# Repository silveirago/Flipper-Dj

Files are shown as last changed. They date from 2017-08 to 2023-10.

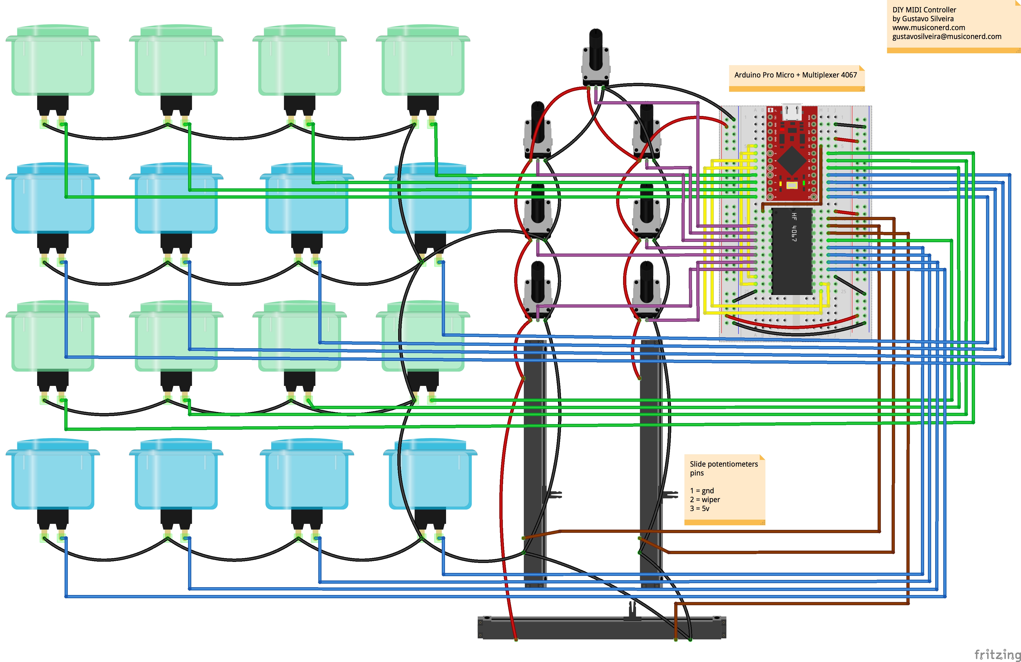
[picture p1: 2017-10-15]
Schematic/Fliper DJ_schematic.jpg

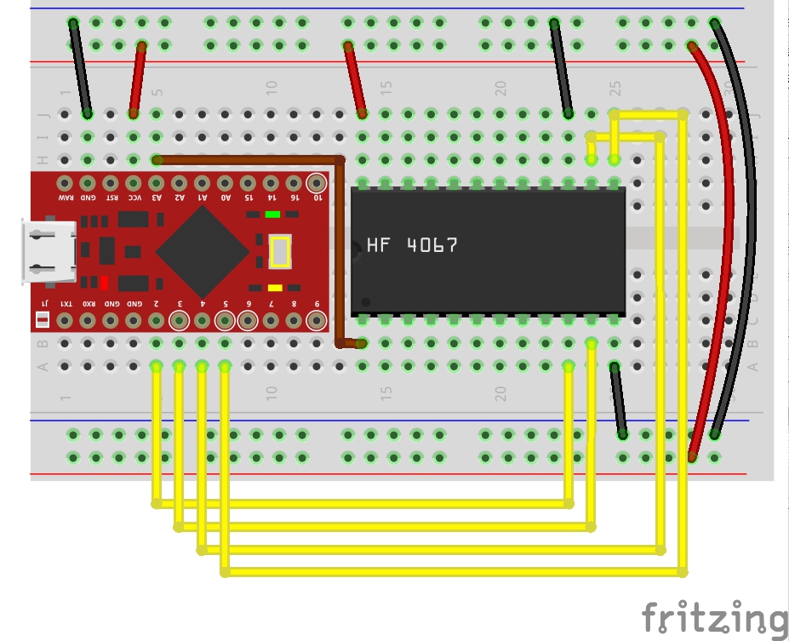
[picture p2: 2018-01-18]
Schematic/CD4067 + Arduino Pro Micro_schematic_bb.jpg

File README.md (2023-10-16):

# Flipper-Dj

Complete tutorial: https://www.musiconerd.com/single-post/Build-this-MIDI-controller-Fliper-Dj

The Fliper DJ is a MIDI controller which is based in the Arduino platform. It contains 16 arcade buttons, 7 rotary potentiometers and 3 slider potentiometers. One of the potentiometers allows you to change the midi channel of the buttons, making it possible to have four banks of buttons, 16x4. The Fliper DJ is a USB-Midi class compliant device, no drivers or converters needed!

Material Needed:

- 16 arcade buttons 30mm
- 7 b10k rotary potentiometers 
- 3 b10k slide potentiometer 30mm (https://www.sparkfun.com/products/11621)
- 1 Arduino Pro Micro
- 1 solderable breadboard (https://www.amazon.com/gp/product/B071R3BFNL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)
- 1 CD40676BE multiplexer
- 5 Spacers M3x35+6mm Female/Male with washers
5 screws M3
- Wires
- 3 guitar pick selector knobs (for the slide pots)
- 7 rotary potentiometer knobs

Some of the items can be found here: https://kit.co/nerdmusician/diy-midi-controller-final-projects-amazon-us

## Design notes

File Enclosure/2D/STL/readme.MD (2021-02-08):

# 3D Printed Enclosures

The files are divided so they fit most beds. Make sure that if you use cura, scale them to 1000%.

Enjoy!

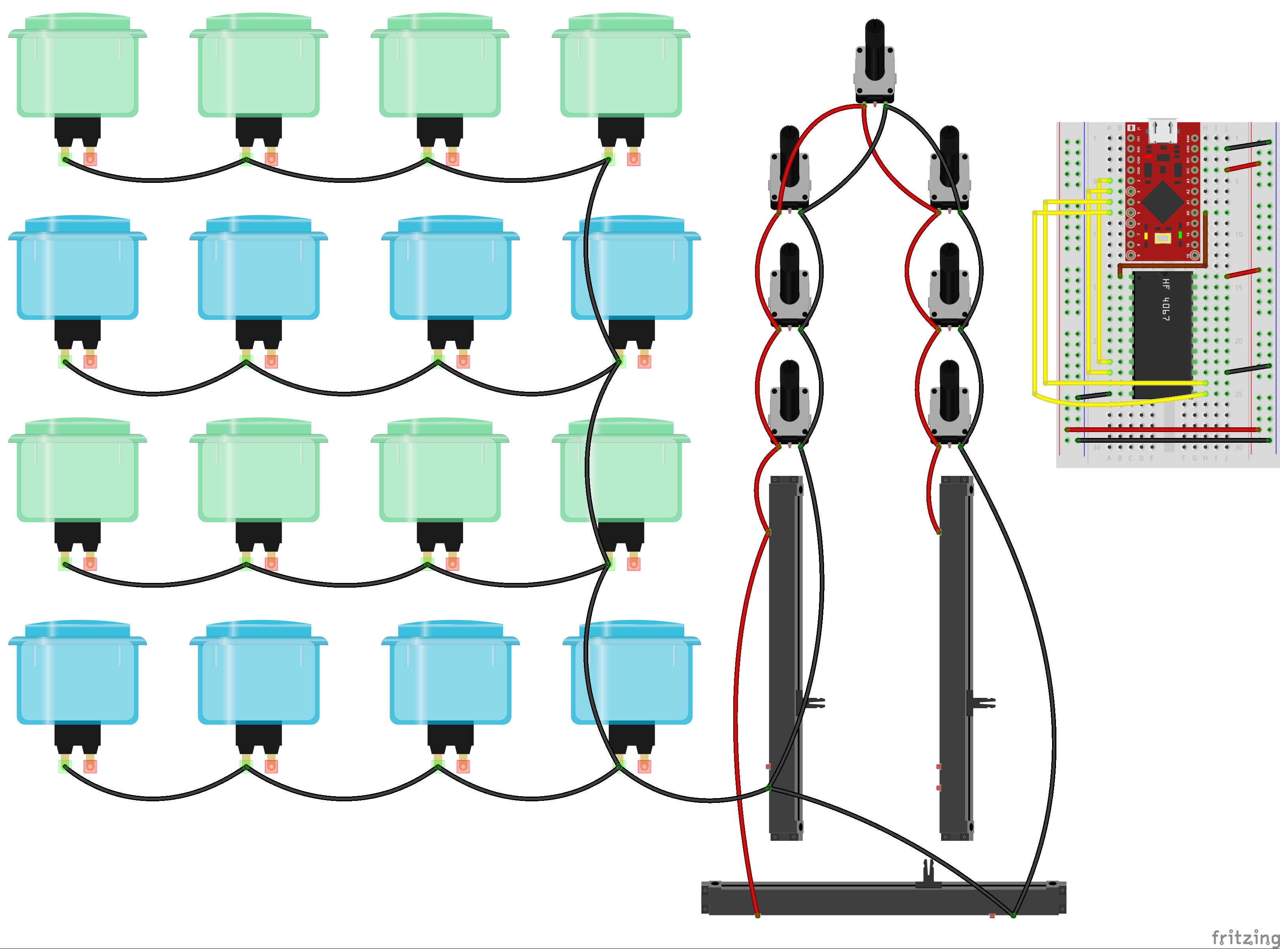
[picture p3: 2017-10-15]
Schematic/Fliper DJ (clean)_schematic.jpg

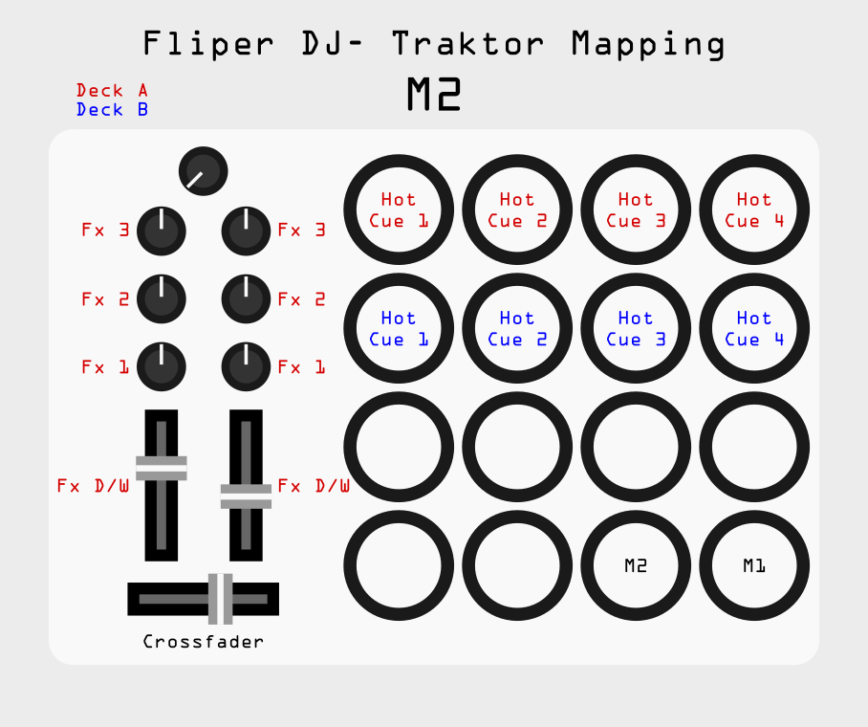
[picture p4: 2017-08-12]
Traktor/Fliper DJ - M2.png

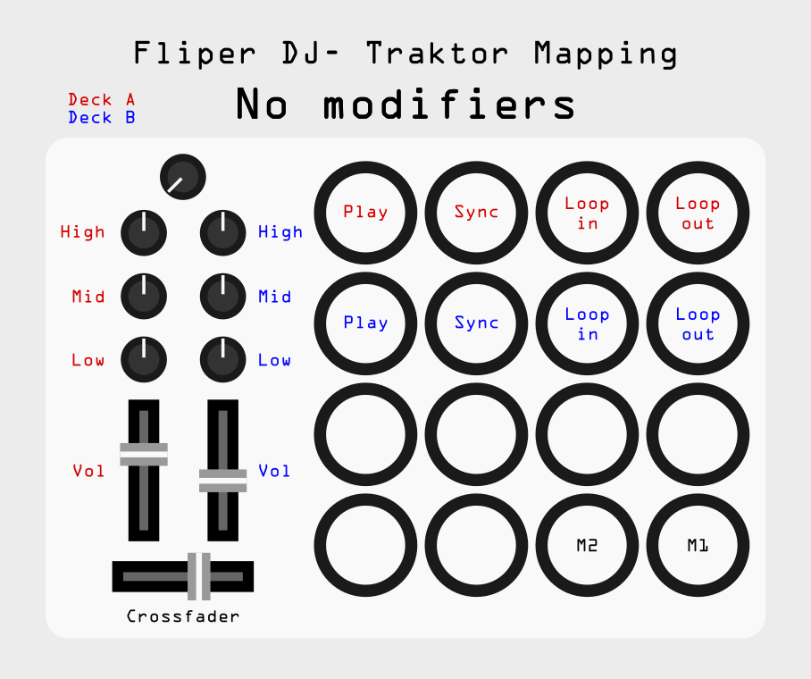
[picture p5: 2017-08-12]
Traktor/Fliper DJ - no modifiers.png

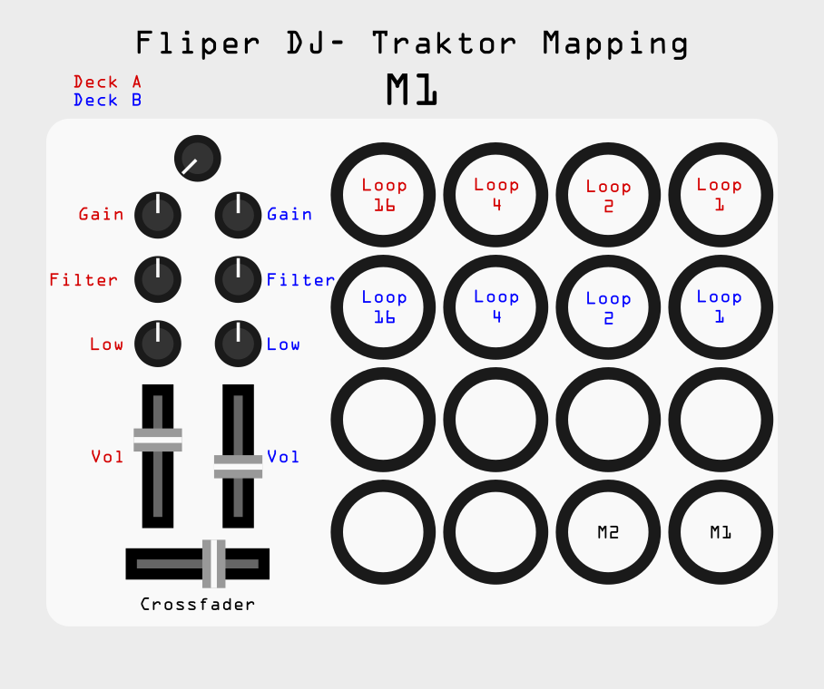
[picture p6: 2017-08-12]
Traktor/Fliper DJ - M1.png

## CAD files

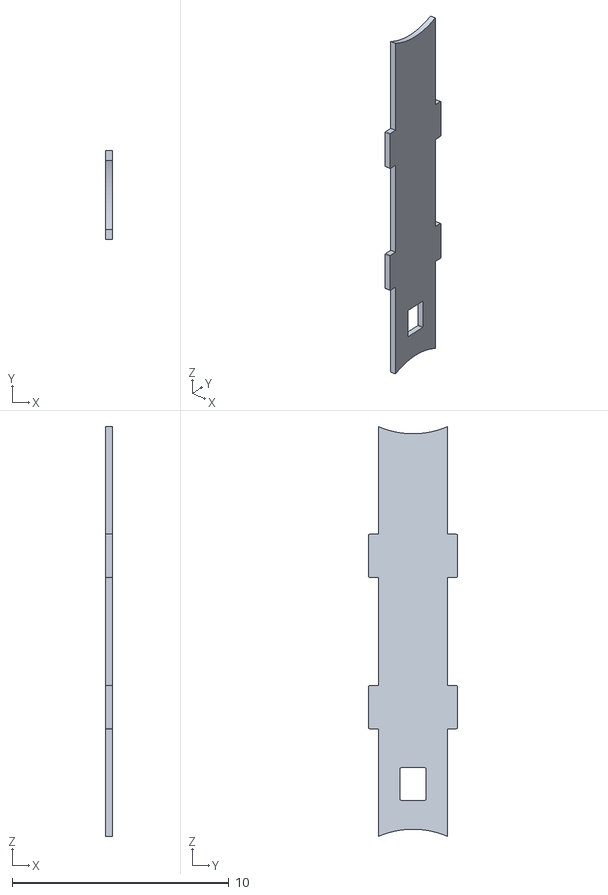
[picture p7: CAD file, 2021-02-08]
Enclosure/2D/STL/side2-print2ofthese.stl
0.3 x 4.10 x 18.9

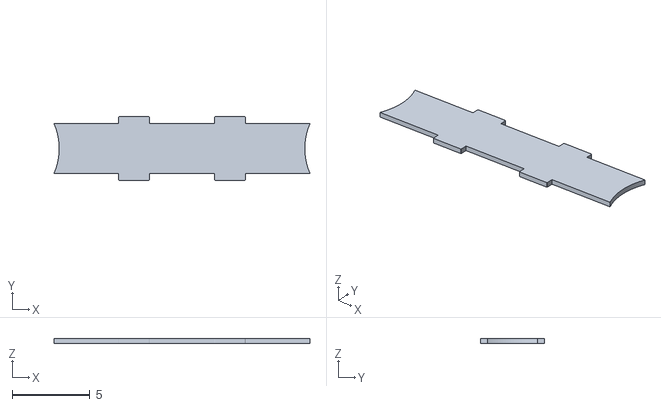
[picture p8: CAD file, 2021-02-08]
Enclosure/2D/STL/side1-print2ofthese.stl
16.5 x 4.10 x 0.3

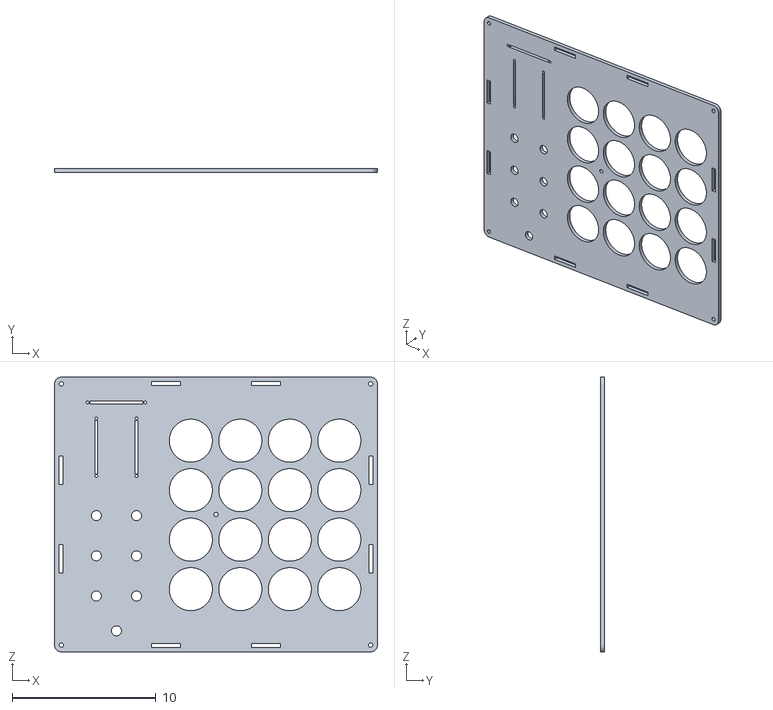
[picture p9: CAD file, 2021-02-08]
Enclosure/2D/STL/top.stl
22.5 x 0.3 x 19.2

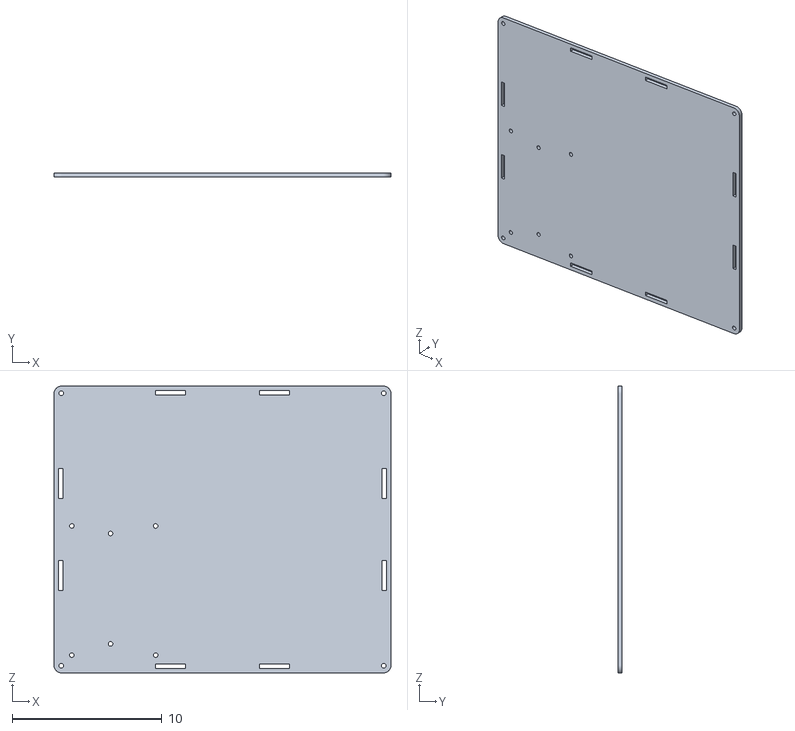
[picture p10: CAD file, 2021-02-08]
Enclosure/2D/STL/bottom.stl
22.5 x 0.3 x 19.2

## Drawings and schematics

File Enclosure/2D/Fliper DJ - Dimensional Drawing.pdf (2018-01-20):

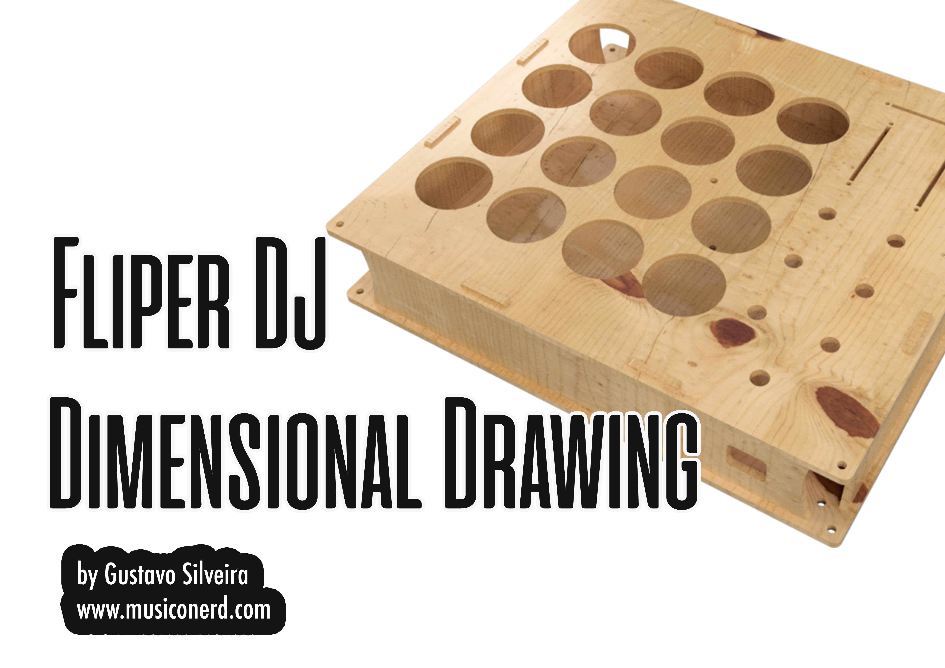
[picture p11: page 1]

A

2 | 3 | 4 | 5 | 6 | 7 | 8

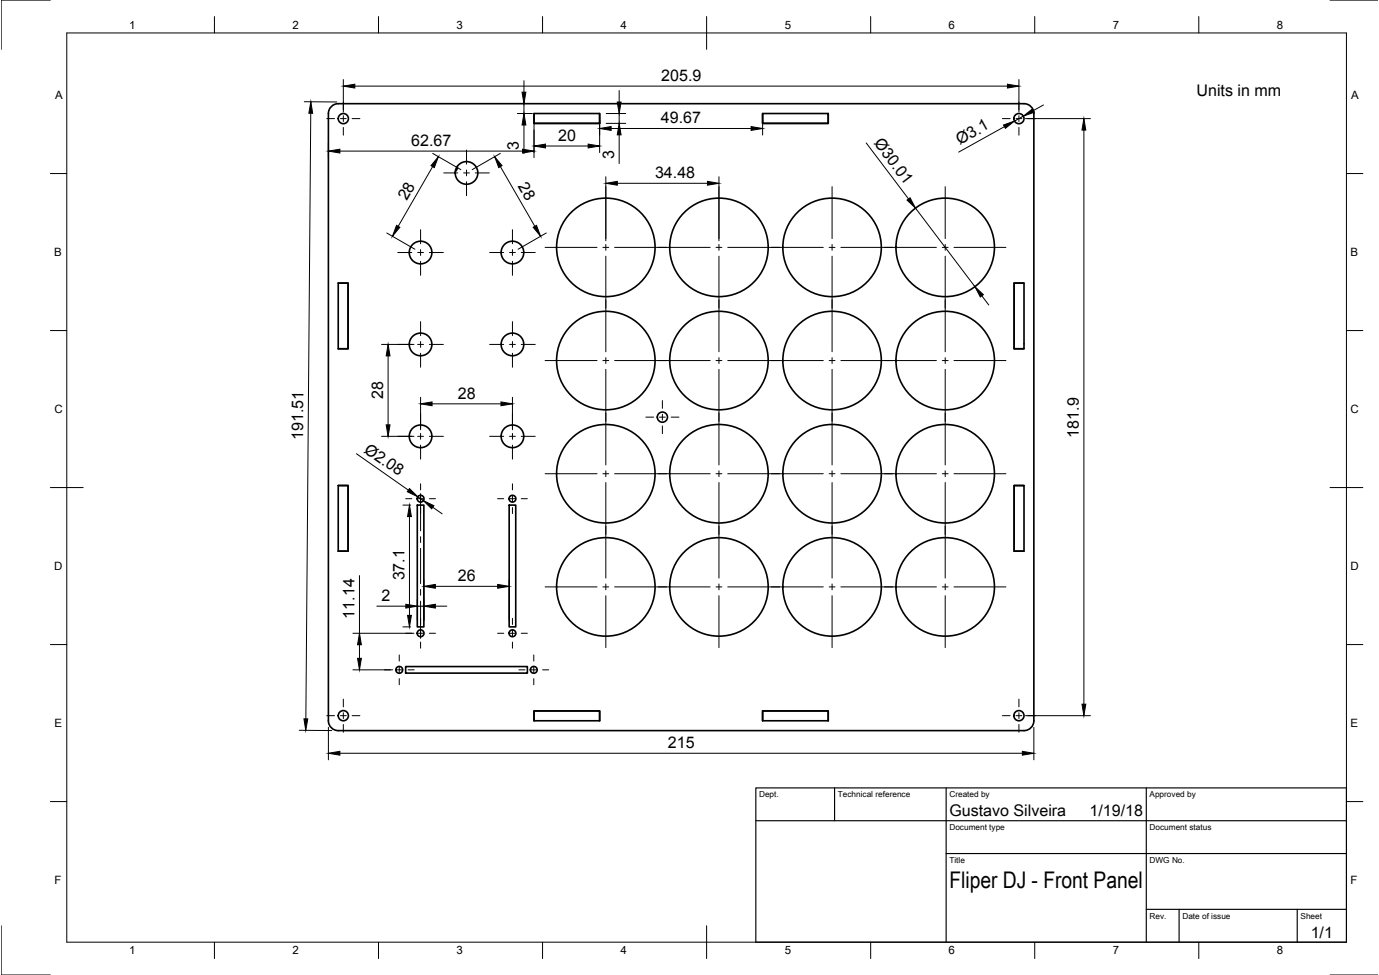
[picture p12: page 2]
Dept.; Technical reference; Created by; Approved by; Document type; Document status; Gustavo Silveira

Units in mm

Title Fliper DJ - Front Panel | DWG No.

Rev. | Date of issue | Sheet

A

A

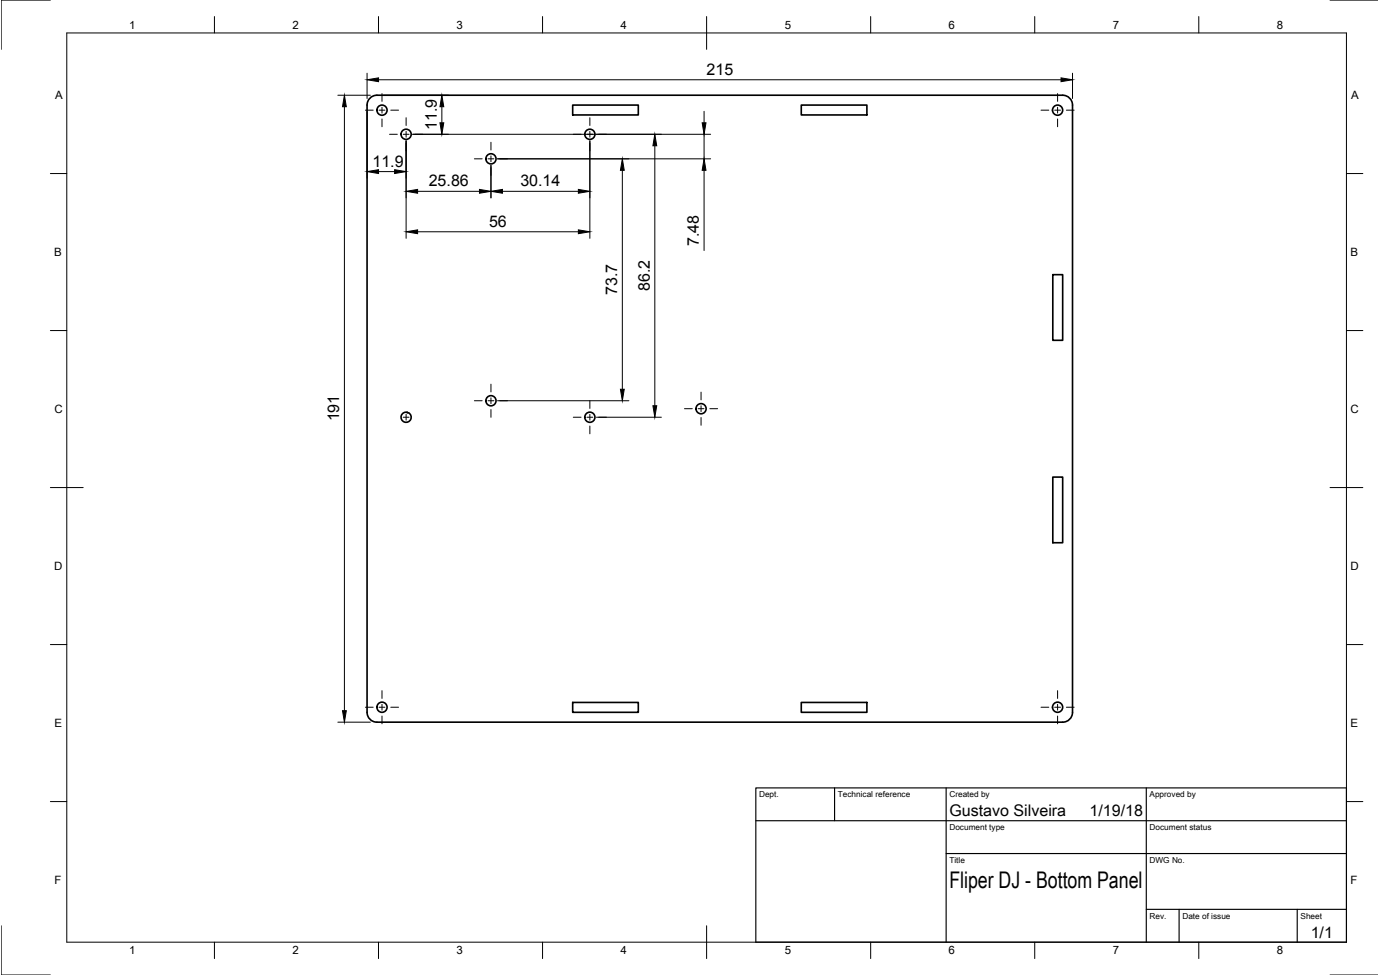
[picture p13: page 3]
Dept.; Technical reference; Created by; Approved by; Document type; Document status; Title; DWG No.; Gustavo Silveira

Fliper DJ - Bottom Panel

A

A

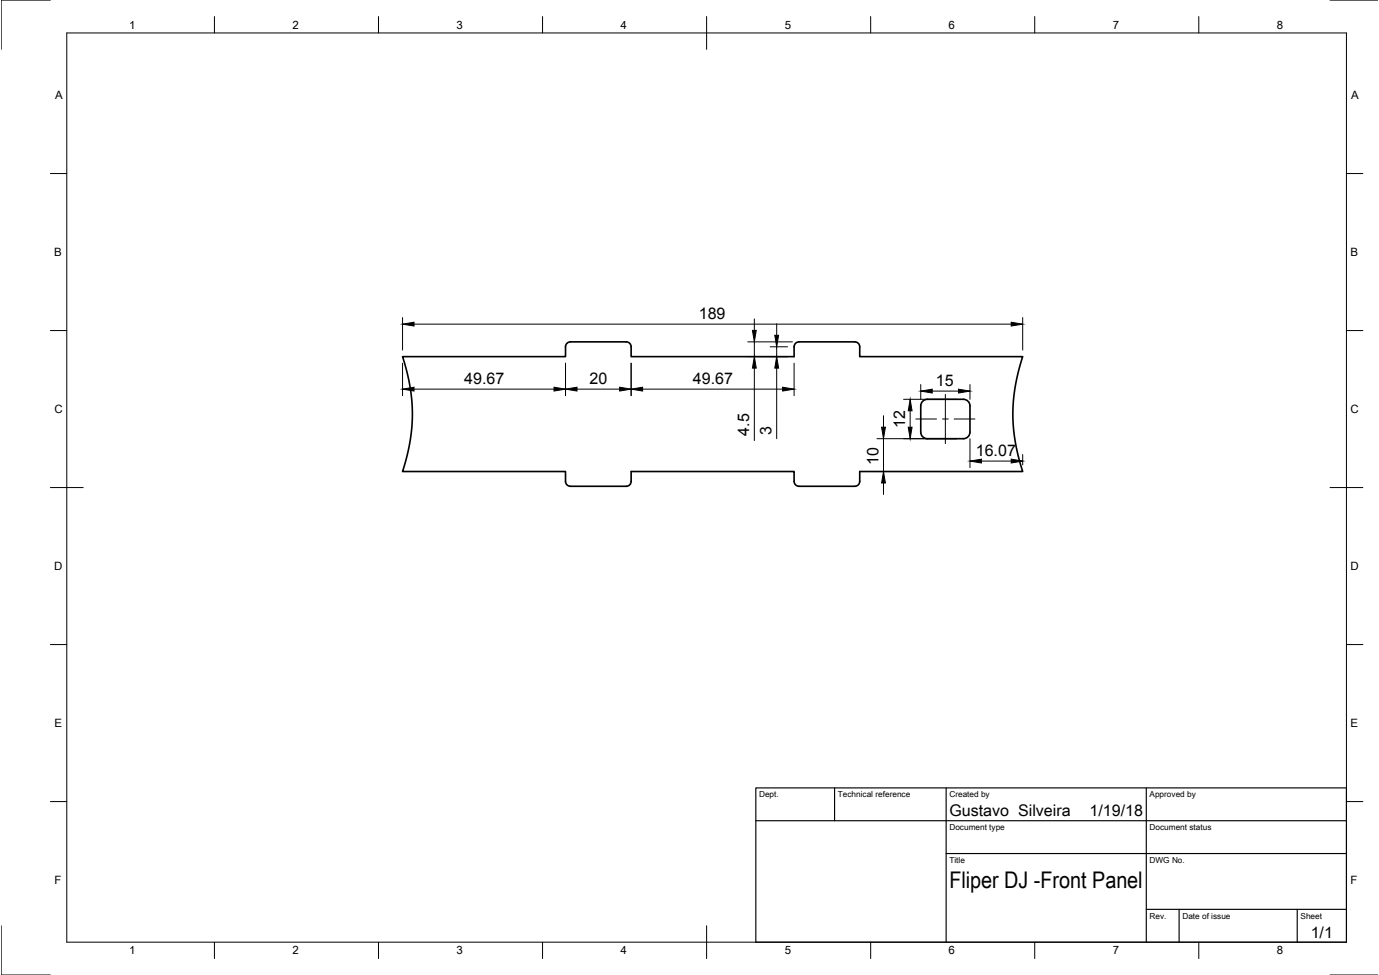
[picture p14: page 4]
Dept.; Technical reference; Created by; Approved by; Gustavo Silveira

Document type | Document status

Title Fliper DJ -Front Panel | DWG No.

A

A

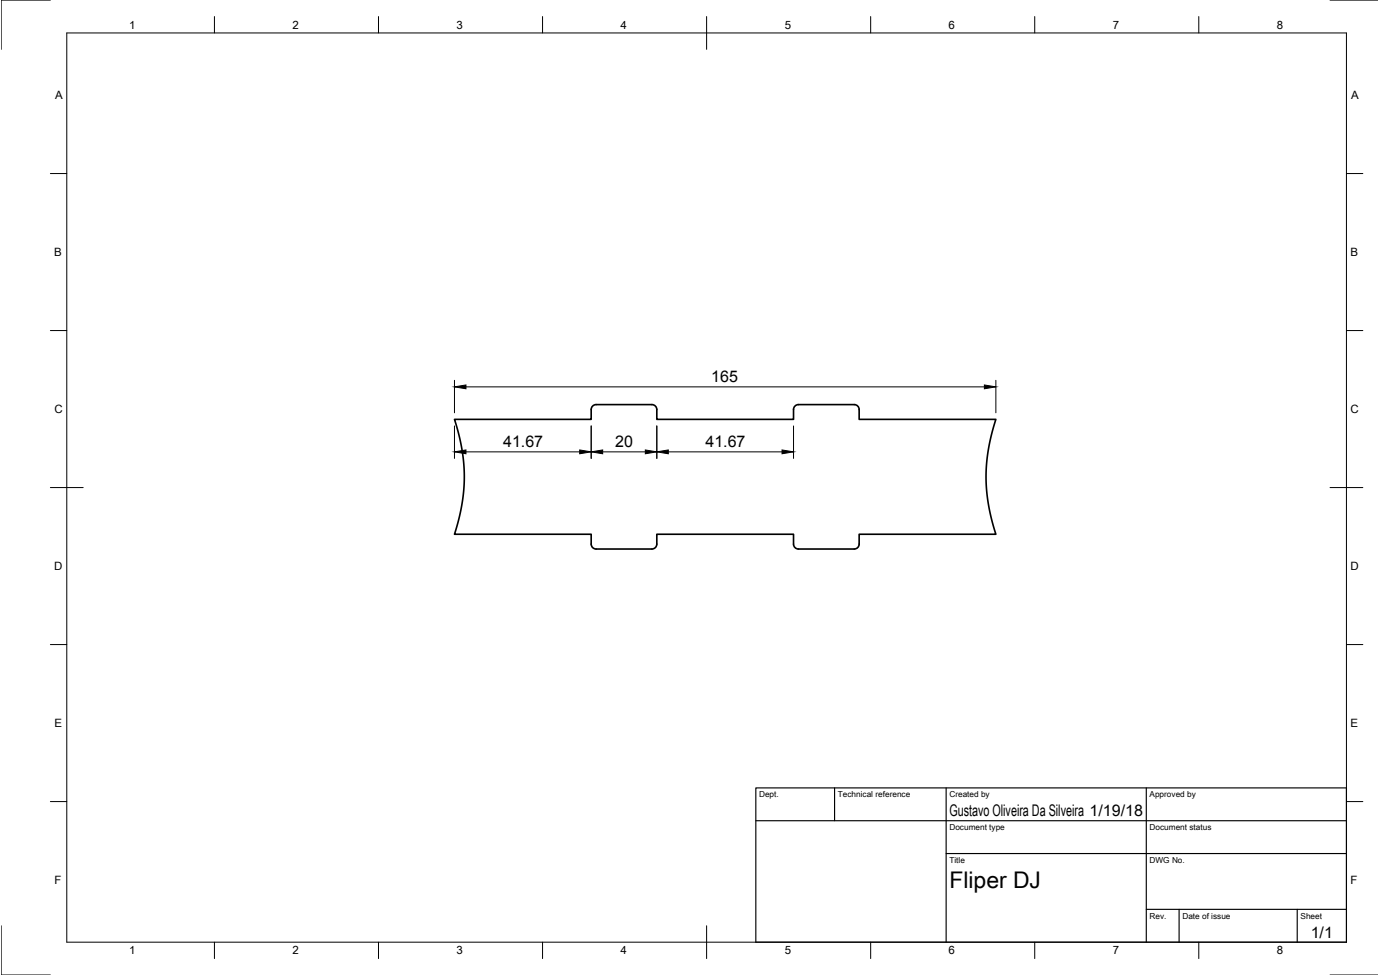
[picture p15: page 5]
Dept.; Technical reference; Created by; Approved by; Document type; Document status; Title; DWG No.; Fliper DJ

Gustavo Oliveira Da Silveira

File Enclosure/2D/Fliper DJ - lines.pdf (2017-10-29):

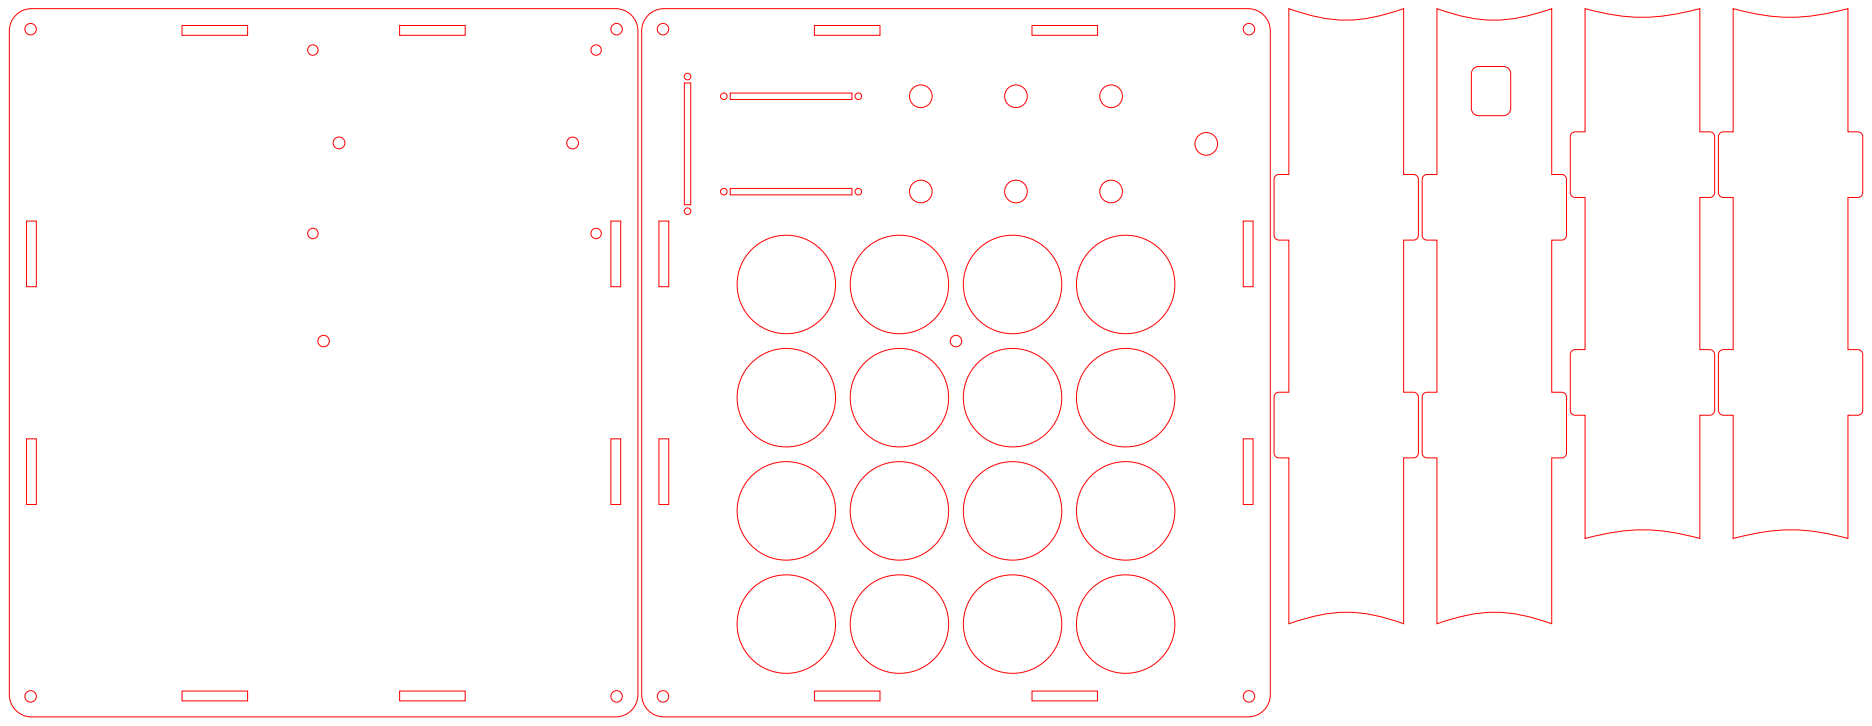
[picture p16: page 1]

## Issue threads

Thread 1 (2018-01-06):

an error code is appearing

lindsaycharles, 2018-01-06:
Arduino: 1.5.7 (Windows 7), Board: "Arduino Micro (arcore)"

sketch_jan06a.ino: In function 'void readButtons()':
sketch_jan06a.ino:127:11: error: 'MidiUSB' was not declared in this scope
sketch_jan06a.ino:134:11: error: 'MidiUSB' was not declared in this scope
sketch_jan06a.ino: In function 'void readPots()':
sketch_jan06a.ino:175:9: error: 'MidiUSB' was not declared in this scope
sketch_jan06a.ino: In function 'void noteOn(byte, byte, byte)':
sketch_jan06a.ino:213:3: error: 'midiEventPacket_t' was not declared in this scope
sketch_jan06a.ino:213:21: error: expected ';' before 'noteOn'
sketch_jan06a.ino:214:3: error: 'MidiUSB' was not declared in this scope
sketch_jan06a.ino: In function 'void noteOff(byte, byte, byte)':
sketch_jan06a.ino:218:3: error: 'midiEventPacket_t' was not declared in this scope
sketch_jan06a.ino:218:21: error: expected ';' before 'noteOff'
sketch_jan06a.ino:219:3: error: 'MidiUSB' was not declared in this scope
sketch_jan06a.ino: In function 'void controlChange(byte, byte, byte)':
sketch_jan06a.ino:223:3: error: 'midiEventPacket_t' was not declared in this scope
sketch_jan06a.ino:223:21: error: expected ';' before 'event'
sketch_jan06a.ino:224:3: error: 'MidiUSB' was not declared in this scope
sketch_jan06a.ino:224:20: error: 'event' was not declared in this scope

  This report would have more information with
  "Show verbose output during compilation"
  enabled in File > Preferences.

silveirago, 2018-01-06:
Can you send me the code?

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

lindsaycharles, 2018-01-06:
I copied the exact code from webpage,
Without changing anything.

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

silveirago, 2018-01-06:
Do you add the libraries?

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

lindsaycharles, 2018-01-07:
Yes
I added all the libraries and the arcore hardware.

On Jan 6, 2018 10:18 PM, "Gustavo Silveira" <notifications@github.com>
wrote:

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

silveirago, 2018-01-07:
Why are you using the Arcore library, I don't use this library in the code.
Maybe you are looking an older version? Can you make sure your are
following this tutorial and using the updated files?

https://www.musiconerd.com/single-post/Build-this-MIDI-controller-Fliper-Dj
https://github.com/silveirago/Flipper-Dj

2018-01-06 22:13 GMT-05:00 lindsaycharles <notifications@github.com>:

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

--
Gustavo Silveira
Composer / Multimedia Artist
www.gustavosilveira.net

lindsaycharles, 2018-01-09:
Yes.
It's working.
I rectified the problem..
But the potentiametres and the sliders are not functioning properly,
I think they are not acting linearly.
Could you help in How to map them in the correct way?.

On Jan 7, 2018 9:22 AM, "Gustavo Silveira" <notifications@github.com> wrote:

Why are you using the Arcore library, I don't use this library in the code.
Maybe you are looking an older version? Can you make sure your are
following this tutorial and using the updated files?

https://www.musiconerd.com/single-post/Build-this-MIDI-controller-Fliper-Dj
https://github.com/silveirago/Flipper-Dj

2018-01-06 22:13 GMT-05:00 lindsaycharles <notifications@github.com>:

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
this
> > scope
> > > > > sketch_jan06a.ino:134:11: error: 'MidiUSB' was not declared in
this
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

> > or mute the thread
> > <https://github.com/notifications/unsubscribe-auth/
> AhipHkLL5aTFX4D0ak3g2im3gXG8tT96ks5tH6PhgaJpZM4RVViM>

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
AOfCqtF3ej1GOq06CD2iSU3QF76BwXD1ks5tIDY9gaJpZM4RVViM>
> .
>

--
Gustavo Silveira
Composer / Multimedia Artist
www.gustavosilveira.net

—
You are receiving this because you commented.
Reply to this email directly, view it on GitHub
<https://github.com/silveirago/Flipper-Dj/issues/1#issuecomment-355797306>,
or mute the thread
<https://github.com/notifications/unsubscribe-auth/AhipHu9NmaZqKf3PT7aAWICBjbAcQD6Pks5tID-IgaJpZM4RVViM>
.

silveirago, 2018-01-09:
They should be linear, independently from the mapping. What exactly is happening?

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

lindsaycharles, 2018-01-11:
When I map them with the Ableton effects, they flicker and always keep
changing the values without being touched

On Jan 9, 2018 11:03 PM, "Gustavo Silveira" <notifications@github.com>
wrote:

They should be linear, independently from the mapping. What exactly is
happening?

> On Jan 9, 2018, at 7:01 AM, lindsaycharles <notifications@github.com>
wrote:
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
wrote:
>
> Why are you using the Arcore library, I don't use this library in the
code.
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
controller-Fliper-Dj
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
notifications@github.com>
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
this
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
this
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
this
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
this
> > > scope
> > > > > > sketch_jan06a.ino:224:20: error: 'event' was not declared in
this
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
thread.
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

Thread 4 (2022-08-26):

My flipboard doesn't work

sleepingcreep, 2022-08-26:
Hello, I followed all the instructions and plugged all the components following the schematics, but the board isn't working. It is recognised as a Midi device in my DAW (Reaper) but none of the buttons nor the potentiometer activate anything.
I tried to go in Serial monitoring, but nothing happens... can you help me to solve this?

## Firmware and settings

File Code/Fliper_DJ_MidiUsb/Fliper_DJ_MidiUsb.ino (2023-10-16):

/* DIY MIDI Controller

Esta sketch permite transformar um Arduino Micro, Pro Micro, ou Leonardo (nao testado),
em um controlador MIDI class compliante. Ou seja, nao ha necessidade de nenhum conversor serial,
como o Hairless Midi.

/// Licensa ///

Este codigo esta licensisado sob forma de "pagamento de cerveja" (se possivel) e 
"dar os devidos creditos" (sempre).

Feito por Gustavo Silveira, 2017.

http://www.musiconerd.com
http://www.bitcontrollers.com
gustavosilveira@musiconerd.com

*/
#include "MIDIUSB.h"
 
#include <Multiplexer4067.h> // Multiplexer CD4067 library >> https://github.com/sumotoy/Multiplexer4067
#include <Thread.h> // Threads library >> https://github.com/ivanseidel/ArduinoThread
#include <ThreadController.h> // Mesma lib de cima
//#include "digitalIOPerformance.h" 

/////////////////////////////////////////////
// buttons
const byte muxNButtons = 5; // *coloque aqui o numero de entradas digitais utilizadas no multiplexer
const byte NButtons = 11; // *coloque aqui o numero de entradas digitais utilizadas
const byte totalButtons = muxNButtons + NButtons;
const byte muxButtonPin[muxNButtons] = {12, 13, 14, 15, 11}; // *neste array coloque na ordem desejada os pinos das portas digitais utilizadas
const byte buttonPin[NButtons] = {18, 19, 20, 10, 16, 14, 15, 6, 7, 8, 9}; // *neste array coloque na ordem desejada os pinos das portas digitais utilizadas
int buttonCState[totalButtons] = {0}; // estado atual da porta digital
int buttonPState[totalButtons] = {0}; // estado previo da porta digital

/////////////////////////////////////////////
// debounce
unsigned long lastDebounceTime = 0;  // the last time the output pin was toggled
unsigned long debounceDelay = 5;    // the debounce time; increase if the output flickers

/////////////////////////////////////////////
// potentiometers
const byte NPots = 10; // *coloque aqui o numero de entradas analogicas utilizadas
const byte muxPotPin[NPots] = {8, 9, 10, 1, 0, 3, 2, 5, 4, 6}; // *neste array coloque na ordem desejada os pinos das portas analogicas, ou mux channel, utilizadas
int potCState[NPots] = {0}; // estado atual da porta analogica
int potPState[NPots] = {0}; // estado previo da porta analogica
int potVar = 0; // variacao entre o valor do estado previo e o atual da porta analogica
int lastCcValue[NPots] = {0};

/////////////////////////////////////////////
// pot reading
int TIMEOUT = 50; //quantidade de tempo em que o potenciometro sera lido apos ultrapassar o varThreshold
byte varThreshold = 4; //threshold para a variacao no sinal do potenciometro
boolean potMoving = true; // se o potenciometro esta se movendo
unsigned long pTime[NPots] = {0}; // tempo armazenado anteriormente
unsigned long timer[NPots] = {0}; // armazena o tempo que passou desde que o timer foi zerado

/////////////////////////////////////////////
// midi
byte midiCh = 0; // *Canal midi a ser utilizado
byte note = 36; // *Nota mais grave que sera utilizada
byte cc = 1; // *CC mais baixo que sera utilizado

/////////////////////////////////////////////
// Multiplexer
Multiplexer4067 mplex = Multiplexer4067(2, 3, 4, 5, A3);

/////////////////////////////////////////////
// threads - programa cada atividade do Arduino para acontecer em um determinado tempo
ThreadController cpu; //thread master, onde as outras vao ser adicionadas
Thread threadReadPots; // thread para controlar os pots

/////////////////////////////////////////////

void setup() {

  mplex.begin(); // inicializa o multiplexer

  for (int i = 0; i < NButtons; i++) { // inicializa os botoes como input utilizando o pull up resistor
    pinMode(buttonPin[i], INPUT_PULLUP);
  }

  pinMode(A3, INPUT_PULLUP);

  /////////////////////////////////////////////
  // threads
  threadReadPots.setInterval(10);
  threadReadPots.onRun(readPots);
  cpu.add(&threadReadPots);
  /////////////////////////////////////////////

}

void loop() {

  cpu.run();
  readButtons();

}


/////////////////////////////////////////////
// read buttons

void readButtons() {

  for (int i = 0; i < muxNButtons; i++) { //reads buttons on mux
    int buttonReading = mplex.readChannel(muxButtonPin[i]);
    //buttonCState[i] = map(mplex.readChannel(muxButtonPin[i]), 22, 1023, 0, 2); // stores on buttonCState
    if (buttonReading > 1000) {
      buttonCState[i] = HIGH;
    }
    else {
      buttonCState[i] = LOW;
    }
    //Serial.print(buttonCState[i]); Serial.print("   ");
  }
  //Serial.println();

  for (int i = 0; i < NButtons; i++) { //read buttons on Arduino
    buttonCState[i + muxNButtons] = digitalRead(buttonPin[i]); // stores in the rest of buttonCState
  }

  for (int i = 0; i < totalButtons; i++) {

    if ((millis() - lastDebounceTime) > debounceDelay) {

      if (buttonCState[i] != buttonPState[i]) {
        lastDebounceTime = millis();

        if (buttonCState[i] == LOW) {
          noteOn(potMidiCh(), note + i, 127);  // Channel 0, middle C, normal velocity
          MidiUSB.flush();
          //MIDI.sendNoteOn(note + i, 127, potMidiCh()); // envia NoteOn(nota, velocity, canal midi)
          //Serial.print("Note: "); Serial.print(note + i); Serial.println(" On");
          buttonPState[i] = buttonCState[i];
        }
        else {
          noteOn(potMidiCh(), note + i, 0);  // Channel 0, middle C, normal velocity
          MidiUSB.flush();
          //MIDI.sendNoteOn(note + i, 0, potMidiCh());
          //Serial.print("Note: "); Serial.print(note + i); Serial.println(" Off");
          buttonPState[i] = buttonCState[i];
        }
      }
    }

  }

}


/////////////////////////////////////////////
//read potentiometers

void readPots() {

  for (int i = 0; i < NPots - 1; i++) { // le todas entradas analogicas utilizadas, menos a dedicada a troca do canal midi
    potCState[i] = mplex.readChannel(muxPotPin[i]);
  }

  for (int i = 0; i < NPots; i++) {

    potVar = abs(potCState[i] - potPState[i]); // calcula a variacao da porta analogica

    if (potVar >= varThreshold) {  //sets a threshold for the variance in the pot state, if it varies more than x it sends the cc message
      pTime[i] = millis(); // armazena o tempo previo
    }
    timer[i] = millis() - pTime[i]; // reseta o timer
    if (timer[i] < TIMEOUT) { // se o timer for menor que o tempo maximo permitido significa que o potenciometro ainda esta se movendo
      potMoving = true;
    }
    else {
      potMoving = false;
    }

    if (potMoving == true) { // se o potenciometro ainda esta se movendo, mande o control change
      int ccValue = map(potCState[i], 22, 1022, 0, 127);
      if (lastCcValue[i] != ccValue) {
        controlChange(11, cc + i, ccValue); // manda control change (channel, CC, value)
        MidiUSB.flush();
        //MIDI.sendControlChange(cc + i, map(potCState[i], 0, 1023, 0, 127), 11); // envia Control Change (numero do CC, valor do CC, canal midi)
        //Serial.print("CC: "); Serial.print(cc + i); Serial.print(" value:"); Serial.println(map(potCState[i], 22, 1023, 0, 127));
        potPState[i] = potCState[i]; // armazena a leitura atual do potenciometro para comparar com a proxima
        lastCcValue[i] = ccValue;
      }
    }
  }

}

/////////////////////////////////////////////
// calculates midi channel based on pot position
int potMidiCh () {
  int potCh =  map(mplex.readChannel(muxPotPin[6]), 22, 1023, 0, 4);

  if (potCh == 4) {
    potCh = 3;
  }
  
  return potCh + midiCh;
}

/////////////////////////////////////////////
// Arduino (pro)micro midi functions Arcore Library
//void noteOn(byte channel, byte pitch, byte velocity) {
//  MIDIEvent noteOn = {0x09, 0x90 | channel, pitch, velocity};
//  MIDIUSB.write(noteOn);
//}
//
//void noteOff(byte channel, byte pitch, byte velocity) {
//  MIDIEvent noteOff = {0x08, 0x80 | channel, pitch, velocity};
//  MIDIUSB.write(noteOff);
//}

/////////////////////////////////////////////
// Arduino (pro)micro midi functions MIDIUSB Library
void noteOn(byte channel, byte pitch, byte velocity) {
  midiEventPacket_t noteOn = {0x09, 0x90 | channel, pitch, velocity};
  MidiUSB.sendMIDI(noteOn);
}

void noteOff(byte channel, byte pitch, byte velocity) {
  midiEventPacket_t noteOff = {0x08, 0x80 | channel, pitch, velocity};
  MidiUSB.sendMIDI(noteOff);
}

void controlChange(byte channel, byte control, byte value) {
  midiEventPacket_t event = {0x0B, 0xB0 | channel, control, value};
  MidiUSB.sendMIDI(event);
}

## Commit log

2017-07-16 Files added
    [CD4067 + Arduino Pro Micro_schematic.fzz, Fliper DJ (clean)_schematic.fzz, Fliper DJ_schematic.fzz]
2017-07-20 Enclosure fix
2017-09-17 Corretions
    The enclosure had some problems in the diting points.
2017-10-05 Schematic updated
    [Fliper DJ_schematic.fzz]
2017-10-08 Enclosure update
    Now the enclosure has mounting holes for two types of solderable breadboards.
    The sparkfun, or gikfun, and the one from PCBoard.ca.
    [Fliper DJ_schematic.fzz]
2017-10-09 Enclosure update
2017-10-15 Shcmatic updated
    [Fliper DJ (clean)_schematic.fzz, Fliper DJ_schematic.fzz]
2017-10-29 Enclosure updated
2017-12-02 Shchematic updated
    [CD4067 + Arduino Pro Micro_schematic.fzz]
2021-02-08 adding STL files
    [bottom.stl, side1-print2ofthese.stl, side2-print2ofthese.stl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]
2023-10-16 materials nedded
2024-02-29 3d files added
    [bottom.stl, side1-print2ofthese.stl, side2-print2ofthese.stl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]
